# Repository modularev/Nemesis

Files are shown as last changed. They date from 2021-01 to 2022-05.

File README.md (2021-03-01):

# Nemesis

## multichannel dsp platform for eurorack 

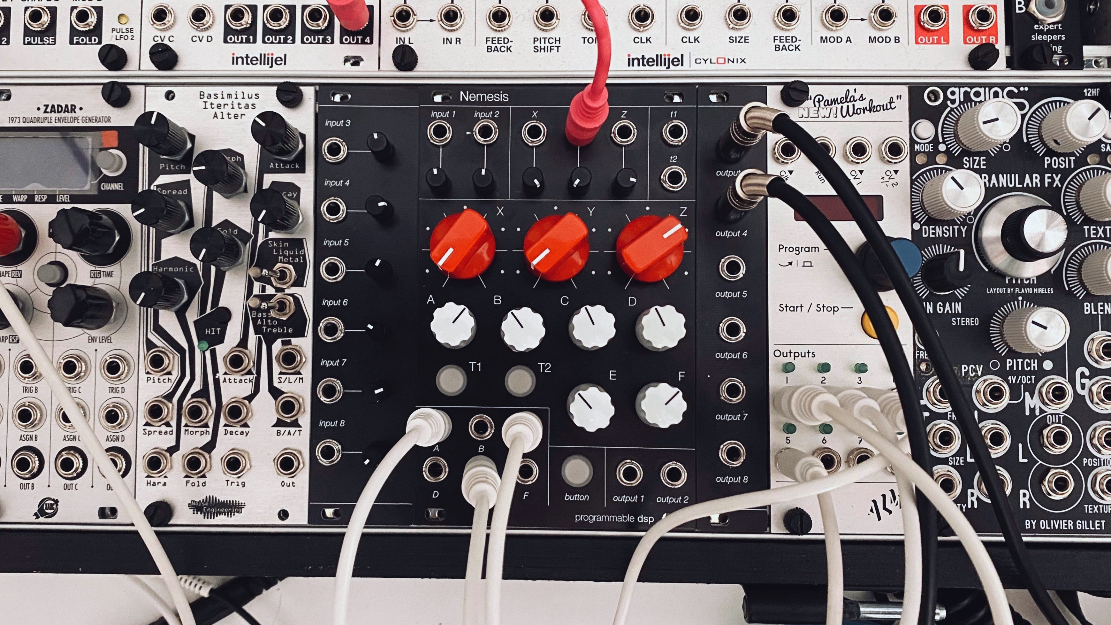
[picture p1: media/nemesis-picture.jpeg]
Panel


**\hardware** bom, gerber, panel, pcb and schematic files

**\software** project template

**\doc** datasheets and additional information

**\media** 

### license

Hardware: 

Software: 

### specifications

- cirrus cs42448 24 bit audio codec (6 in / 8 out) with additional cs5343 (2 in) 
- teensy 4.1 (arm cortex-m7 at 600 mhz) with 512kb usable `DMAMEM` (can be extended with 2x ESP-PSRAM64 for additional 16mb `EXTMEM`)

- cv Inputs X Y Z with attenuverter
- inputs A-F configurable as cv (0-10V) <u>or</u> ac coupled audio inputs (passive, audio ch. 3-8)
- 2 ch audio in ac or dc coupled with up to 18db gain (full scale at noon 10vpp)
- 2 ch audio out ac or dc coupled (+-5v) 
- **input module:** 6 ac or dc coupled audio-rate inputs with attenuators
- **output module:** 6 ac or dc coupled active audio-rate outputs

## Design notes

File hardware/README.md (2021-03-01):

# Nemesis hardware
**\bom** bill of materials

**\frontpanel** illustrator files for the frontpanel

**\gerber** gerber files for production

**\pcb** diptrace schematic and board layout

**\pdf** schematic in pdf format

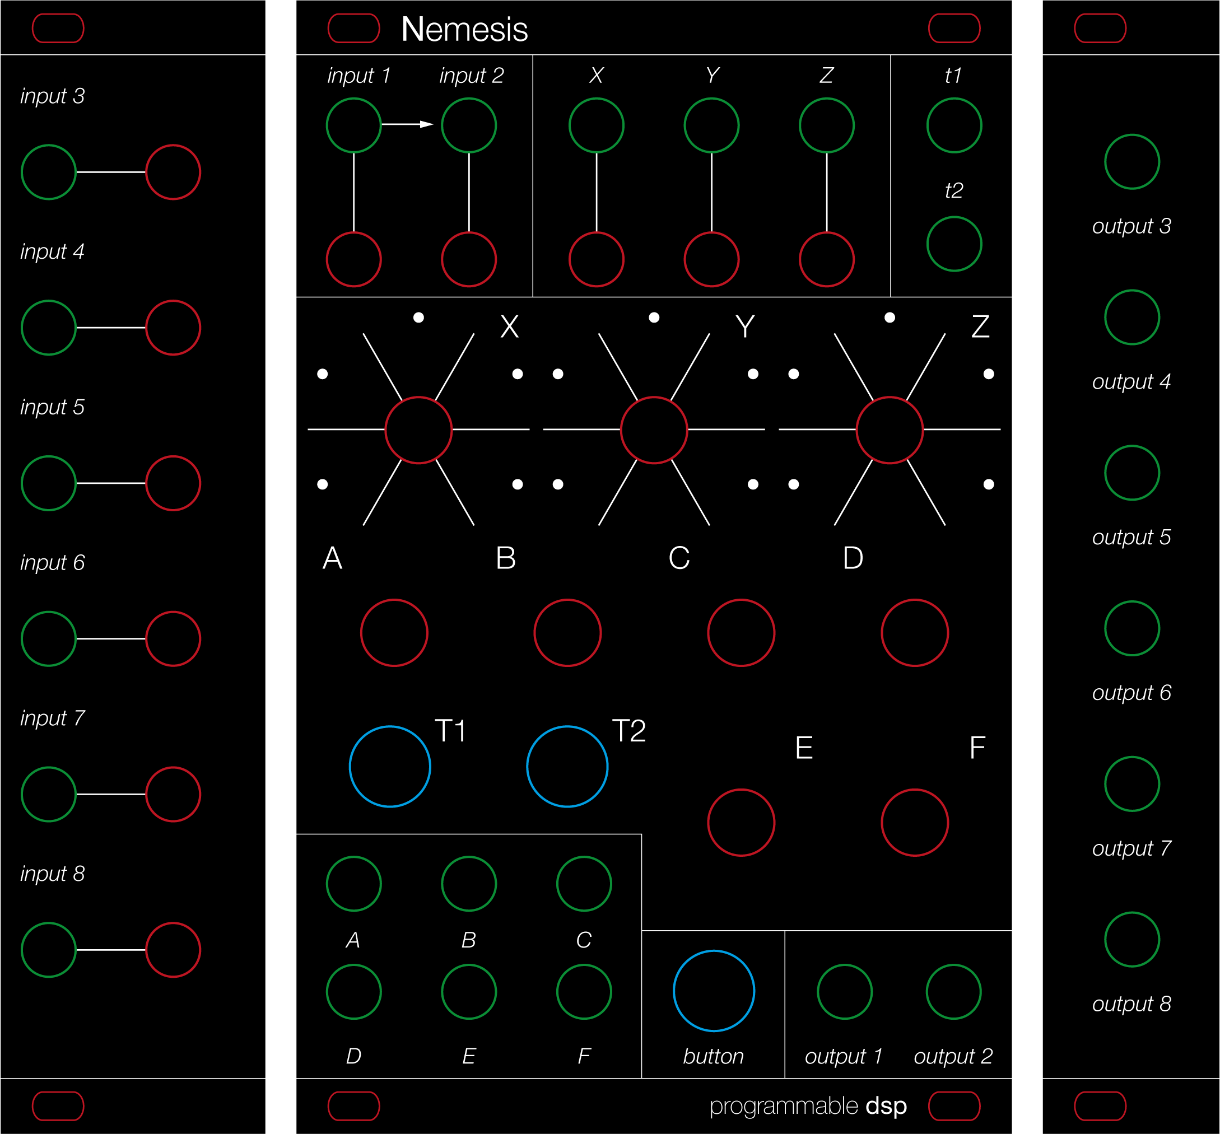
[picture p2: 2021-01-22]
media/nemesis-panel.png

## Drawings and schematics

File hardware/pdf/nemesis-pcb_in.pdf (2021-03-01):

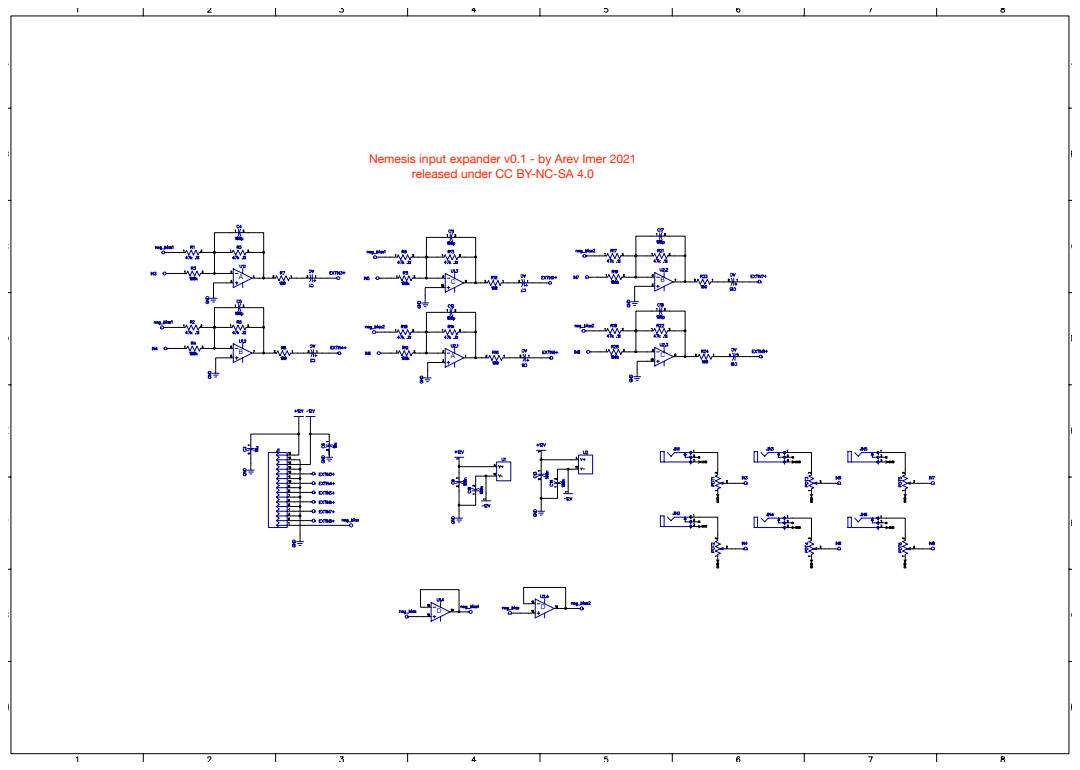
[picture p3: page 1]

Nemesis input expander v0.1 - by Arev Imer 2021
released under CC BY-NC-SA 4.0

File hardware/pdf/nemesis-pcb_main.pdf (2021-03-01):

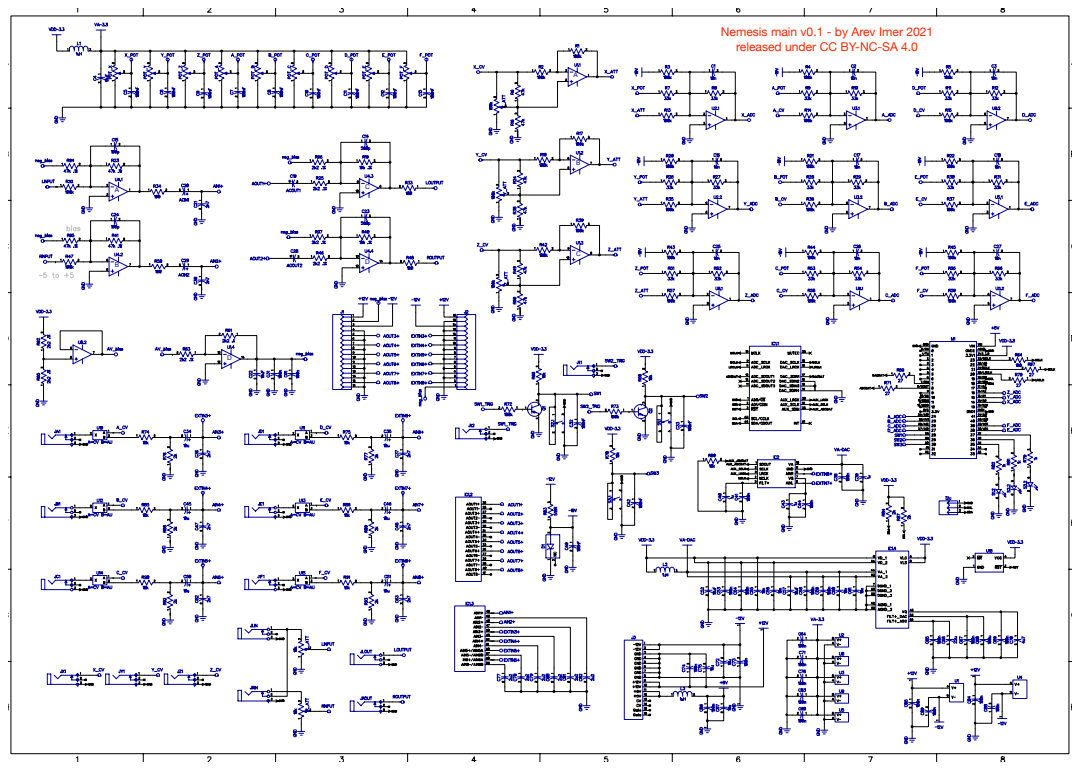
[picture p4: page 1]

Nemesis main v0.1 - by Arev Imer 2021
released under CC BY-NC-SA 4.0

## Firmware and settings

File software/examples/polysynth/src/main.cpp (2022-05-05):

#include <SerialFlash.h>
#include <SD.h>
#include <SPI.h>
#include <Wire.h>
//#include <elapsedMillis.h>
#include "nemesis_hw.h"
#include <utility/imxrt_hw.h>
#include "mono_voice.h"
#include <typeinfo>

// Audio Connections
//
// AudioInputTDM audio_in;
AudioOutputTDM audio_out;
mono_voice faustObj;

#ifdef HIGHRES
// AudioConnection Lin_MSB(audio_in, 0, faustObj, 0);
// AudioConnection Lin_LSB(audio_in, 1, faustObj, 1);
// AudioConnection Rin_MSB(audio_in, 2, faustObj, 2);
// AudioConnection Rin_LSB(audio_in, 3, faustObj, 3);
AudioConnection Lout_MSB(faustObj, 0, audio_out, 0);
AudioConnection Lout_LSB(faustObj, 1, audio_out, 1);
AudioConnection Rout_MSB(faustObj, 2, audio_out, 2);
AudioConnection Rout_LSB(faustObj, 3, audio_out, 3);
// AudioConnection ch3out_MSB(faustObj, 4, audio_out, 4);
// AudioConnection ch3out_LSB(faustObj, 5, audio_out, 5);
// AudioConnection ch4out_MSB(faustObj, 6, audio_out, 6);
// AudioConnection ch4out_LSB(faustObj, 7, audio_out, 7);
#else
// AudioConnection Lin_MSB(audio_in, 0, faustObj, 0);
// AudioConnection Rin_MSB(audio_in, 2, faustObj, 1);
AudioConnection Lout_MSB(faustObj, 0, audio_out, 0);
AudioConnection Rout_MSB(faustObj, 1, audio_out, 2);
#endif

//
// Parameters from Faust
//

// #ifdef MIDICTRL
// const char *polyAddress = "/Polyphonic/Voices/";
// #endif

using namespace nemesis;

int param_count = 0;
std::string hwParams[11] = {
    "CV_X",
    "CV_Y",
    "CV_Z",
    "CV_A",
    "CV_B",
    "CV_C",
    "CV_D",
    "POT_A",
    "POT_B",
    "POT_C",
    "POT_D",
};

extern unsigned long _heap_end;
extern char *__brkval;
uint32_t FreeMem(){ // for Teensy 4.1
  char* p = (char*) malloc(100000); // size should be quite big, to avoid allocating fragment!
  free(p);
  return (char *)&_heap_end - p; // __brkval;
}

float returnVal(int hw_num)
{
   switch (hw_num)
   {
   case 0:
      return cv_val[0];
   case 1:
      return cv_val[1];
   case 2:
      return cv_val[2];
   case 3:
      return cv_val[3];
   case 4:
      return cv_val[4];
   case 5:
      return cv_val[5];
   case 6:
      return cv_val[6];
   case 7:
      return pot_val[0];
   case 8:
      return pot_val[1];
   case 9:
      return pot_val[2];
   case 10:
      return pot_val[3];
   default:
      return 0;
   }
}

#include <vector>

std::vector<std::pair<std::string, int>> param;

void pathFinder()
{
   for (int i = 0; i < 11; i++)
   {
      for (int p = 0; p < faustObj.getParamsCount(); ++p)
      {
         size_t found = faustObj.getParamAddress(p).find(hwParams[i]);
         if (found != std::string::npos)
         {
            param.emplace_back(std::make_pair(faustObj.getParamAddress(p), i));
            break;
         }
      }
   }
   param_count = param.size();
}

void getParamArgs()
{

   for (int p = 0; p < param_count; ++p)
   {
      Serial.print(param[p].first.c_str());
      Serial.print("\t");
      Serial.println(param[p].second);
   }
}

void setup()
{
   Serial.begin(19200);
   setPSRAMspeed();

   pinMode(led_pin[0], OUTPUT);
   digitalWrite(led_pin[0], HIGH);
   pinMode(9, OUTPUT);

   pinMode(led_pin[1], OUTPUT);
   digitalWrite(led_pin[1], HIGH);

   display.begin(SSD1306_SWITCHCAPVCC, 0x3C);

   display.clearDisplay();
   display.setTextSize(1);
   display.setTextColor(WHITE);
   display.setFont(&SourceCodePro_ExtraLight6pt7b);
   display.setCursor(0, 7);
   display.print(F("say hello to"));
   display.display();

   display.setCursor(0, 31);
   display.setFont(&SourceCodePro_ExtraLightItalic14pt7b);
   display.print(F(">NEMESIS"));
   display.display();
   display.setFont(&SourceCodePro_ExtraLight6pt7b);
   delay(2000);

   for (int i = 0; i < POT_NUM; i++)
   {
      pinMode(pot_pin[i], INPUT_DISABLE);
   }

   // Setup both adc modules on teensy
   adc->adc0->setAveraging(ADC_AVERAGING);                          // set number of averages
   adc->adc0->setResolution(ADC_RES);                               // set bits of resolution
   adc->adc0->setConversionSpeed(ADC_CONVERSION_SPEED::MED_SPEED);  // change the conversion speed
   adc->adc0->setSamplingSpeed(ADC_SAMPLING_SPEED::VERY_LOW_SPEED); // change the sampling speed
   // adc->adc0->recalibrate();

   adc->adc1->setAveraging(ADC_AVERAGING);                          // set number of averages
   adc->adc1->setResolution(ADC_RES);                               // set bits of resolution
   adc->adc1->setConversionSpeed(ADC_CONVERSION_SPEED::MED_SPEED);  // change the conversion speed
   adc->adc1->setSamplingSpeed(ADC_SAMPLING_SPEED::VERY_LOW_SPEED); // change the sampling speed
   // adc->adc1->recalibrate();

   // for (int i = 0; i < 4; i++)
   // {
   //    pot_adc[i].init(pot_pin[i], TB_US, 500);
   //    pot_adc[i].enable();
   // }

   initADC();

   // POT_ADC_TIMER.begin(scan_POT, 1000); //
   // POT_ADC_TIMER.priority(230);

   // CV_ADC_TIMER.begin(scan_CV, 100); // 25kHz
   // CV_ADC_TIMER.priority(230);

   // OLED_REFRESH.begin(displayadc, 20000); // 50Hz
   // OLED_REFRESH.priority(255);

   digitalWrite(9, HIGH);
   AudioMemory(64); // 832 max
   codec.enable();
   codec.write(0x03, 0xF4 | 0x01);
   codec.write(0x05, 0x00);
   //codec.filterFreeze();
   codec.volume(1.);
   // init_POT();
   // while (!Serial)
   // {
   //    ;
   // }
   pathFinder();
   getParamArgs();
}

void update()
{
   for (int p = 0; p < param_count; ++p)
   {
      //delay(100);
      // Serial.print(returnVal(param[p].second));
      // Serial.print("\t ");
      faustObj.setParamValue(param[p].first, returnVal(param[p].second));

   }
   Serial.println(AudioProcessorUsageMax());
}
int i = 0;
void loop()
{
   scan_POT();
   scan_CV();
   update();

   if (i < 500)
      i++;
   else
   {
      displayadc();
      i = 0;
   }
   // delay(1);
}

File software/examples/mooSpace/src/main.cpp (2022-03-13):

#include <SerialFlash.h>
#include <SD.h>
#include <SPI.h>
#include <Wire.h>
//#include <elapsedMillis.h>
#include "nemesis_hw.h"
#include "mooSpace.h"
//#include "TeensyDebug.h"
//#pragma GCC optimize ("O0")
//
// Audio Connections
//
AudioInputTDM audio_in;
AudioOutputTDM audio_out;
mooSpace faustObj;

#ifdef HIGHRES
AudioConnection Lin_MSB(audio_in, 0, faustObj, 0);
AudioConnection Lin_LSB(audio_in, 1, faustObj, 1);
AudioConnection Rin_MSB(audio_in, 2, faustObj, 2);
AudioConnection Rin_LSB(audio_in, 3, faustObj, 3);
AudioConnection Lout_MSB(faustObj, 0, audio_out, 0);
AudioConnection Lout_LSB(faustObj, 1, audio_out, 1);
AudioConnection Rout_MSB(faustObj, 2, audio_out, 2);
AudioConnection Rout_LSB(faustObj, 3, audio_out, 3);
#else
AudioConnection Lin_MSB(audio_in, 0, faustObj, 0);
AudioConnection Rin_MSB(audio_in, 2, faustObj, 1);
AudioConnection Lout_MSB(faustObj, 0, audio_out, 0);
AudioConnection Rout_MSB(faustObj, 1, audio_out, 2);
#endif

//
// Parameters from Faust
//
const char *param[] = {
    "smear",           // POT X
    "decay",           // POT Y
    "drag",            // POT Z
    "Filter",          // POT A
    "input diffusion", // POT B
    "colour",          // POT C
    "lag",             // POT D
    "push",            // POT E
    "mix"};            // POT F

//
// Variables
//

// uint16_t adc_new[9];
// uint16_t adc_old[9];
// float fValue[9];

// constexpr float smoothing = 0.2f;

// elapsedMicros hysteresis[9];

//
//
//
void print_audio_usage()
{
   // Serial.print(AudioProcessorUsage());
   // Serial.print("\t");
   // Serial.print(faustObj.processorUsage());
   // Serial.print("\t");
   //Serial.println(AudioMemoryUsageMax());

   for (int i = 0; i < 4; i++)
   {
      Serial.print("POT " + i);
      Serial.print("\t");
   }

   Serial.print("\n");

   for (int i = 0; i < 4; i++)
   {
      Serial.print(nemesis::pot_val[i]);
      Serial.print("\t");
   }

   for (int i = 0; i < 7; i++)
   {
      Serial.print("CV " + i);
      Serial.print("\t");
   }

   Serial.print("\n");

   for (int i = 0; i < 7; i++)
   {
      Serial.print(nemesis::cv_val[i]);
      Serial.print("\t");
   }
}

void send_params(int i)
{ // !!!RANGE IS INVERTED!!!
   // fValue[i] = -(float)(adc_new[i] - nemesis::getADC_min(i)) / (float)(nemesis::getADC_min(i) - nemesis::getADC_max(i));
   // if (fValue[i] > 0.994)
   // {
   //    fValue[i] = 1.0;
   // }
   // else if (fValue[i] < 0.006)
   // {
   //    fValue[i] = 0.0;
   // }
   // faustObj.setParamValue(param[i], clamp(fValue[i]));
}

void setup()
{
   Serial.begin(19200);
   //debug.begin(SerialUSB1);
   //halt();                    

   //while (!Serial);
   // nemesis::setSampleRate((int)AUDIO_SAMPLE_RATE_EXACT);
   nemesis::init();
   //nemesis::calibration(); // calibration routine

   // if (EEPROM.read(0) == 0xFF) // check for calbration flag
   // {
   //    //nemesis::loadCalibration();
   //    Serial.println("Calibration loaded!");
   // }
   // else
   //    Serial.println("No calibration found!");

   // for (int i = 0; i < 9; i++)
   // {
   //    pinMode(analog_pin[i], INPUT_DISABLE);
   // }

   //analogReadResolution(9);
   //analogReadAveraging(8);
   // codec.invertDAC(0x3F);
   // codec.invertADC(0x3F);
   // delay(200); // wait for dc offset to stabilize
   // codec.filterFreeze();
   // myTimer.begin(print_audio_usage, 500000);
   nemesis::codec.volume(1.0);
}

void update()
{
   nemesis::scan_CV();
   nemesis::scan_POT();
   faustObj.setParamValue(param[0], nemesis::cv_val[0]);
   faustObj.setParamValue(param[1], nemesis::cv_val[0]);
   faustObj.setParamValue(param[2], nemesis::cv_val[0]);
   faustObj.setParamValue(param[3], nemesis::cv_val[1]);
   faustObj.setParamValue(param[3], nemesis::cv_val[1]);
   faustObj.setParamValue(param[4], nemesis::cv_val[2]);
   faustObj.setParamValue(param[5], nemesis::pot_val[0]);
   faustObj.setParamValue(param[6], nemesis::pot_val[1]);
   faustObj.setParamValue(param[7], nemesis::pot_val[2]);
   faustObj.setParamValue(param[8], nemesis::pot_val[3]);
   // for (int i = 0; i < 9; i++)
   // {
   //    adc_new[i] = adc_new[i] + smoothing * (analogRead(pot_pin[i]) - adc_new[i]);
   //    if (abs(adc_new[i] - adc_old[i]) > 3 || hysteresis[i] < 100)
   //    {
   //       adc_old[i] = adc_new[i];
   //       adc_new[i] = adc_new[i];
   //       send_params(i);
   //       hysteresis[i] = 0;
   //       // Serial.print(i);
   //       // Serial.print("\t");
   //       // Serial.println(fValue[i], 3);
   //    }
   // }
}



void loop()
{
   nemesis::displayadc();
   //update();
}

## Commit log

2021-03-01 add license & schematic pdf
    added hardware license cc by-nc-sa 4.0
    added schematic pdf
2021-11-23 filter test
2021-11-24 smooth adc
2021-11-24 filter work
2022-02-23 add i2c lib
2022-05-06 update adc for hw1
2026-10-21 WIP snapshot before repository reorganisation
    Uncommitted work found in the working tree: polysynth experiments
    (.bdsp parked programs, superosc), frontpanel artwork, plus the
    codecWrite() workaround and mooSpace -midi removal so both examples
    build against Teensyduino 1.59.
2026-10-21 Sort hardware files by revision
    - hardware/{pcb,pdf,gerber} and the euro_dsp panel artwork -> hardware/rev1
    - rev2/ and the nemesis_22/23 panel artwork -> hardware/rev2
    - loose artwork in the repo root moved next to its panel files
    (euro_dsp.ai -> rev1/frontpanel/euro_dsp-2022-01.ai,
    nemesis_22.ai -> rev2/frontpanel/nemesis_22-2022-01.ai)
    - stop tracking DXVK shader caches; replace the catch-all '.*' ignore
    rule with explicit patterns
2026-10-21 Unify rev1 and rev2 software in a shared library and in-repo FAUST toolchain
    software/lib/nemesis: one hardware library for both revisions, selected
    with -D NEMESIS_HW_REV=1|2 (PlatformIO environments rev1/rev2)
    - rev1 ported from moospace-filtertank: 9 knob+CV inputs on Teensy
    analog pins, EEPROM min/max calibration (hold button 3 at power up)
    - rev2 ported from polysynth: LTC1867 CV inputs, pots, OLED monitor
    - the library owns the TDM patching and binds FAUST parameters to
    inputs via label prefix ("CV_X: Pitch") or metadata ([hw:CV_X],
    [rev1:CV_C] [rev2:POT_A])
    - codec registers written over I2C, AudioControlCS42448::write() is
    private in stock Teensyduino
    software/faust: archite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
2026-11-02 rev2: fix LTC1867 timing, LED and DAC polarity
    Measured on rev2 hardware with an ES-10 as DC source and a loopback from
    the codec outputs into the CV inputs:
    - LTC1867L CV ADC ran at 24 MHz in SPI mode 1 with 5 us per channel,
    outside the datasheet (max 10 MHz for rising edge capture, SDI hold
    time, 3.7 us conversion + 2.01 us acquisition). Every input read a flat
    spot of ~100 mV at mid scale. Now mode 0, 10 MHz, 8 us per channel:
    all 7 inputs linear to ~5 mV.
    - push button LEDs are active high
    - the codec output stages invert, enable the CS42448 DAC channel invert
    so +1 is +5 V (all 8 outputs DC coupled, +-5 V)
2026-11-02 rev2: background pot reading, knob calibration, encoder, rawInput()
    - pots are read in the ADC conversion complete interrupt with 32x
    hardware averaging (best noise per time in measurements: ~1.1 LSB in
    66 us vs 24-33 LSB for a single reading) and an adaptive one pole
    filter (slow while resting, fast while turned). Resting pots hold to
    0.1-0.2 LSB; the main loop no longer blocks on the ADC.
    - knob calibration stored in EEPROM: hold both buttons for 2 s (or
    button 1 at power up), turn the knobs through their range, button 2
    stores. Inputs that weren't moved stay uncalibrated.
    - encoder on pins 4/5 with push switch on pin 6 (found with
    tests/pinscan): encoderPosition() in clicks,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
2026-11-02 Add rev2 hardware test firmware
    - hwtest: OLED bars for all inputs, buttons, encoder; serial readout
    (calibrated and raw); button LEDs; audio pass-through plus a DC level
    per output set over serial
    - pinscan: finds the Teensy pins of an unknown control (used to locate
    the encoder)
    - adcnoise: pot ADC noise and timing per ADC setting
2026-11-02 Add CV and output measurement script (cvtest)
    cvtest.py drives DC levels through DC coupled audio interface outputs
    (ES-10 on a Fireface UFX here) and reads the module over USB serial:
    hold (measure the source with a multimeter), sweep (gain, offset,
    linearity, channel order, crosstalk of every CV input) and dac (codec
    outputs measured in loopback through the CV inputs). cv_fit.json holds
    the rev2 CV input fits from 2026-11-02.
2026-11-02 rev2: volt calibration for CV inputs and outputs
    - CV inputs: per channel reading at 0 V and per volt, stored in EEPROM.
    Calibrated input() reads 0..1 = 0..8 V on A-D and -4..+4 V on X/Y/Z
    (gain only, their zero is set by the main knob); cvVolts() returns
    volts. The knob calibration now only covers POT A-D.
    - outputs: per channel volts per unit and offset, applied by the FAUST
    architecture file (nemesis::outputCorrection) so 1.0 is 5 V and 0 is
    0 V for every program; rev1 keeps them uncorrected.
    - set/store/reset/print API for the measurement tools
    Measured on the rev2 test unit: CV inputs within +-2.5 mV, outputs
    within +-2 mV after calibration (uncorrected gains differed by up t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
2026-11-02 cvtest: calibrate CV inputs and outputs, hwtest calibration commands
    - cvtest.py calibrate-inputs: sweeps every CV input with the ES-10
    (corrected per ES-10 output with the multimeter readings), stores the
    fits in the module and checks A-D at 1/4/7 V
    - cvtest.py calibrate-outputs: measures outputs in loopback through the
    calibrated CV inputs, stores and checks them; refuses outputs without
    signal
    - hwtest: CVCAL, OUTCAL, CALSTORE, CALRESET, CALSHOW serial commands and
    a VOLTS line
    - cv_fit.json updated with the corrected CV fits
2026-11-03 rev2: known hardware issues and the main board schematic
    KNOWN_ISSUES.md collects what the measurements on the rev2 test unit
    showed, with fixes for the next revision: audio inputs 1-4 can't pass
    DC (AINx- only AC grounded through 2.2 uF; IN 5/6 can in single ended
    mode), input range per codec mode, IN 7/8 AC only (CS5343), MIDI input
    (6N137 run at 3.3 V, TRS type B wiring), output offsets, OUT 5 jack,
    CV input ranges, LTC1867 timing, encoder pins, pot ADC noise.
2026-11-03 Program switching, poly effects and robustness in library and FAUST arch
    - programs start lazily (start()/started()): DSP, memory and bindings are
    created on first selection; nemesis::begin(list), selectProgram(), the
    last program is stored after it ran 3 s, holding the encoder (rev2) or
    button 1 (rev1) at power up starts the first one
    - rev2 display: program and CPU load, program list on the encoder
    - faust_build.py: custom_faust_programs list, generated
    nemesis_programs.h, 'effect' of polyphonic programs compiled as a
    second class and run after the voice mix (dsp_poly_effect), RTTI for
    all programs as soon as one is polyphonic (mixed RTTI crashed in
    __dynamic_cast)
    - teensy41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
2026-11-03 Firmware with several programs, juno polysynth, mooSpace rev2 mapping
    - software/firmware: juno, mooSpace, freqshift, superosc in one firmware
    at 816 MHz with USB MIDI + serial, PROG/CONTROLS/STATUS commands
    - software/programs/juno.dsp: 6 voice Juno style synth (DCO saw, pulse
    with PWM, sub, noise, HPF, moogLadder VCF, ADSR, LFO, chorus I/II as
    poly effect), ~10 % CPU per voice
    - software/programs/freqshift.dsp from the parked polysynth programs
    - mooSpace 0.4: rev2 knobs + CV for Filter, modulate, colour, mix (CV
    jacks without knobs read 0 when unpatched); modulate is a slow subtle
    wobble instead of a 133 Hz saw, noon is off
    - all projects upload with teensy-gui (teensy-cli faile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
2026-11-03 tests: audio input meters, HP 34401A and loopback calibration
    - hwtest: DC level and sine per output, DC/RMS meters on all 8 audio
    inputs, raw codec register writes, parameter listing
    - cvtest.py: calibrate-outputs-dmm (outputs against an HP 34401A),
    calibrate-inputs-loopback (CV inputs from the calibrated outputs),
    audio-inputs and codec-mode measurements
    - requirements.txt for the test tool venv (Python 3.12)
2026-11-03 Add working notes for development sessions
    CLAUDE.md: tools, devices, upload and debug workflow and the pitfalls
    found so far, so a new session doesn't have to rediscover them.
2026-11-03 rev2: settings menus on the encoder, settings on SD, knob popup
    - Turning a knob shows the name and value of its parameter for a moment
    (X/Y/Z included; an input that keeps moving, i.e. patched modulation,
    is ignored until it rests).
    - Encoder: turn opens the program settings (parameters without a knob,
    CV A-D routing to any parameter), click the program list, press and
    hold the system settings (MIDI channel, knob popup, brightness,
    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
2026-11-03 breaker: beat slice repeat/reverse program with crush, comb and drive
    Stereo breakbeat processor on a MIDI clock (Start resets to the
    downbeat) or the internal tempo: slices repeat (rolls when shortened
    while repeating) or play reversed, by gate (CV A/B) or chance (Y/Z),
    followed by bit crush, comb filter and drive. Out 3/4 give slice and
    beat triggers, the display shows clock source and tempo, LED 1 the beat,
    LED 2 repeats.
    Firmware: breaker added as program 5, serial commands MEM (PSRAM size)
    and GET <path> (parameter or meter of the running program).
2026-11-03 Folder cleanup: all FAUST programs in software/programs
    - mooSpace and superosc moved to programs/, unfinished programs (bell,
    mono_voice, polySynth) to programs/sketches (not built); the old copy
    of freqshift and an early draft of superosc removed
    - examples/ removed; single/ builds one program from programs/ as its
    own firmware, for rev1 (no display or encoder) or to try a program
    - programs/README.md lists every program with its rev1/rev2 controls
2026-11-04 Library: system transport, program memory, output stage
    - Transport for all programs (nemesis.lib): internal tempo or MIDI clock,
    tracked by a PLL from timestamped ticks; MIDI jack and USB MIDI read in
    a 100 us timer; system settings clock, tempo, run, offset
    - Program switching frees non-MIDI programs; delay lines up to 32 KB go to
    a 192 KB RAM1 arena (mooSpace 65 -> 56 % CPU); fixed delete order and
    a ready flag against crashes while switching
    - Output setting for every program (clip/soft/tape/fold) on its audio
    outputs, 'declare output' and 'declare audio_outputs' per program
    - Clip detection always on, limiter gain on the home screen; metadata
    [volts:1], [mono:note|gate|veloc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
2026-11-04 superosc: drone with MIDI note, V/Oct, limiter, pitch CV and gate outs
    The oscillator sum scales down when root + fourth + fifth exceed the
    default mix, so resonance no longer drives the limiter to -8 dB.
2026-11-04 breaker: drum triggers from a pattern map, rev-rep knob, bipolar comb
    - Outs 3-8: kick, snare, closed/open hi-hat, perc 1/2 triggers from a
    4x4 map of one bar patterns (POT C/D + CV C/D), blended between the
    corners; density, swing and trigger length settings
    - Y: reverse (left) / repeat (right) chance, centre off
    - Z: comb with feedback and pitch together, negative feedback on the left
    - Output setting defaults to clip
2026-11-04 mooSpace2: v1 algorithm with wider controls and a motion setting
    Drag up to 2x, low smear lowers the diffusion, deeper modulation, colour
    also before the tank, filter make-up gain, limiter. Motion: tank delays
    glide (pitch) or crossfade (no pitch). 67 % CPU on the module.
2026-11-06 Direct TDM audio: half the round trip latency
    Programs read and write the CS42448's TDM DMA buffers directly: one 32 bit
    word per channel and frame instead of 16 bit MSB/LSB Audio library blocks.
    Subclasses of AudioInputTDM/AudioOutputTDM find the private buffers via
    the DMA registers and take over the DMA interrupts: the receive interrupt
    hands this cycle's input to the program (it got the previous one, the
    programs update before the TDM input), the program writes the transmit half
    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
2026-11-06 Less memory: -dlt 16384, os.oscs instead of os.osc
    Delays above 16384 samples get their exact length (mooSpace2 1141 ->
    1059 kB, freqshift 1 MB -> 512 kB). superosc's 24 drift LFOs no longer
    read os.osc's 256 kB sine table in PSRAM.
2026-11-06 growler: mono FM bass voice
    Feedback FM (modulator ratio and feedback into a feedback carrier),
    wavefolder, ladder filter, decay envelope on index and cutoff, wobble LFO
    synced to the transport, clean sub; MIDI or V/Oct + CV gate, wobble and
    envelope CV outs. Program 7, 14 % CPU.
2026-11-06 freqshift: oscillator outputs at 4.9 V, no constant CLIP
2026-11-06 freqshift: oscillator outputs at 4.75 V
    0.98 still clipped on 7/8 on the module: the output calibration's offset
    pushes one side beyond the DAC range. Measured: no clipped samples at 0.95.
2026-11-09 Library: block size at runtime, clock on IN 8, menus, CV targets, note slots
    - Block size per program or system setting (auto/32/64/128): the SAI stops
    at a frame end, both DMA loops get the new length, everything restarts in
    sync; 'declare block_size'. Loopback 88/152/280 samples at 32/64/128,
    channels keep their slots. CPU display relative to the real block.
    - Clock source IN 8: clock/gate edges found in the audio samples, 1/4..1/16
    or 24 ppqn, through the transport PLL; pulses after a pause restart at
    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
2026-11-09 Docs: block size, IN 8 clock, note slots, CV B-D zero, measurements
2026-11-09 Library: Michroma/Oxanium fonts, [name:]/[if:]/[ifnot:] settings, block size not stored
    - Display fonts: Michroma 16 px (program names), Michroma 13 px oblique
    (knob popup, splash), Oxanium 10 px (menus, header), converted with
    fonts/ttf2gfx.py; OFL licenses next to them. Source Code Pro removed.
    - [name:lag] shows a setting under another name (labels stay unique for
    the SD card), [if:sync] / [ifnot:sync] lists it only while another
    setting is on / off; the list is rebuilt when that setting changes.
    - The block size system setting is no longer stored: every power up
    starts with auto (the program's declared size, else 64).
2026-11-09 mooSpace2 2.8: tone, reverse, shimmer, sync, freeze, echoes, 8 outputs
    - tone in the tank (colour + lp/hp in one), reverse on POT A, shimmer
    (pitch shifter where input and feedback enter the tank) on POT B,
    modulate as an assignable setting
    - soft limiters instead of the tank compressors (no pumping), an extra
    fixed allpass per tank half
    - smear = diffuser strength, drag = diffuser lengths and late taps;
    eight input diffusers capped at 0.6, so transients fade in
    - decay knob = tail time (0.4..60 s exponential, endless above 0.95)
    - sync: reverse pieces and late taps on the tempo; lag in ms or note
    values; motion on/off, crossfade fixed at 25 ms; the crossfade heads'
    take triggers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
2026-11-11 Library: safe start, presets, runtime sample rate, own MIDI and polyphony
    Robustness
    - RTWDOG watchdog (4 s), boot failure counter in EEPROM: after 2 starts
    that ended within 10 s, program 1 with the SD card off; the program is
    stored for the next start only after 10 s
    - settings files read at most 32 kB (more: renamed BAD_), written to .NEW
    and renamed when complete
    - every program is freed on a switch: vectors swapped empty, FAUST's MapUI
    replaced by a lookup on demand (strike's start ran the heap out)
    Programs and the display
    - knob catch with saved knob values, a pager setting (button 1), audition
    (button 2), sections, rolls ([action:roll]: history, turn back),
    [edit:], [tit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
2026-11-11 pollen and strike: live granulator and modal percussion
    pollen 0.3: live granulator after Multigrain: a loop memory per channel
    (2^20 samples, 10.9 s at 96 kHz) that freeze holds, 8 grain voices with
    position, size, pitch, density, spray, reverse, shapes, blur reverb (also
    on the input), free or synced to the transport; the frozen loop is saved
    on the SD card and loaded when the program starts frozen. 96 kHz.
    strike 0.6: 6 voice modal percussion after Plonk, triggers on IN 1-6 and
    MIDI (a channel or note per voice): modes per voice (4-6), exciter with
    noise, tension, bend, rattle, choke; a page per voice (button 1),
    audition (button 2), rolls of random settings, X/Y/Z assignable macros,
    POT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
2026-11-11 juno 0.12: cheaper voices, Juno-106 patches, drift
    - voices: one polyBLEP ramp for saw and pulse, a half rate ramp for the
    sub, a TPT ladder with its coefficient from a table, soft saturated
    input, self-oscillation (started by a short noise burst near it), bass
    compensation for resonance; 12 voices at 48 kHz, 6 at 96 kHz (72/77 %)
    - drift: per voice detune and filter offset, per note, slow wander
    - the Juno-106's parameters: LFO delay, VCA level and env/gate, range,
    PWM mode, env polarity, HPF positions 0-3 (bass boost), envelope and
    LFO ranges from the owner's manual, pitch bend, fixed pan per voice
    - patch: presets from /NEMESIS/juno.PRE; tools/juno106_presets.py converts
    a Jun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
2026-11-11 Docs: supply, heap, MIDI and polyphony, sample rate, presets, programs
    KNOWN_ISSUES: the Teensy's 1117 5 V regulator was too weak (resets and a
    freeze under strike's load; now fed from the bus +5 V), pot spikes.
2026-11-11 juno 0.15: fitted to a recording of A11, factory patch order
    - ranges from the Juno-106 owner's manual and service notes: filter
    5 Hz-50 kHz, envelope +14 octaves, LFO to the VCF +-3.5 octaves, to the
    DCO +-400 cents, LFO 0.1-30 Hz, envelope 1.5 ms-3 s / 12 s
    - RC envelope (straight attack, exponential decay and release); the
    slider time is 2 time constants and the cutoff slider's 0 sits at 113 Hz
    at C4, both fitted to a recording of factory patch A11 (its brightness
    curve within 0.28 octaves)
    - HPF positions 0-3 with the bass boost, chorus off/I/II/I+II as a setting,
    pitch bend +-2 semitones, self-oscillation started by a short noise burst
    - juno106_presets.py writes the factory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
2026-11-11 Docs: juno ranges, envelope and filter fit, factory order
2026-11-12 Display: encoder gestures, [home:1] setting, USB name Nemesis
    - home screen: turn = the program's [home:1] setting (its value big, the
    program name moves up; without one the settings open), click = settings,
    hold = program list, hold there = system settings, also the settings
    list's last row "system >"
    - the top line moves right when its first letter reaches left (juno's j)
    - USB product name "Nemesis" (name.c): the MIDI port's name in DAWs
2026-11-12 juno 0.17: the Juno-106's measured curves, pulse phase, keys, home patch
    - measured slider curves from Ultramaster KR-106 via Youth106 (GPL-3.0) in
    juno106_curves.lib: cutoff 5.7 Hz-50 kHz, attack and decay/release times,
    LFO rate and delay, DCO LFO depth, sub and noise levels; the cutoff added
    up in slider units as the firmware (envelope, LFO, key follow), the
    resonance curve and peak pull, HPF 236/754 Hz and the bass boost circuit,
    the chorus's delays, rates and dry/wet, VCA level +-10 dB
    - pulse in phase with the saw (the 106's comparator; inverted, saw + pulse
    partly cancelled), the 106's oscillator mix
    - output -16 dB (chords of the factory patches peaked at +10 dBFS) and a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
2026-11-12 Docs: encoder gestures, polyphony, juno's curves, USB name

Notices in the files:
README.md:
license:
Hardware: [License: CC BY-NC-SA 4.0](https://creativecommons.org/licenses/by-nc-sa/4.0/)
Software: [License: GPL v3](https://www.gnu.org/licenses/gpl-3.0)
